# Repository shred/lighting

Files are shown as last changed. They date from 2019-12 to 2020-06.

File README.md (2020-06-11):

# Wall Bias Lighting

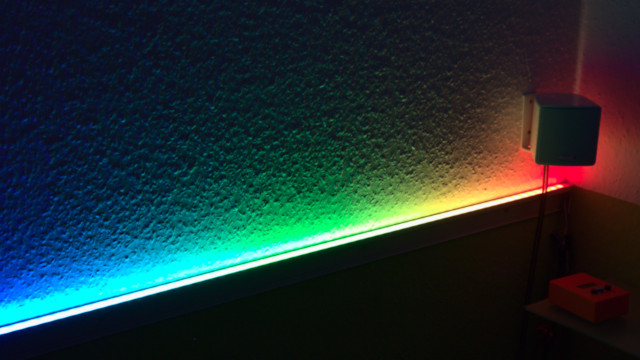
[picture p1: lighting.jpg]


This is a DIY wall bias lighting.

It uses an RGBW LED strip (based on SK6812 LEDs), where every LED can be addressed individually.

# Construction

The lighting consists of a controller module based on an Adafruit [Feather M0 Express](https://www.adafruit.com/product/3403), and a separate RGBW LED strip.

The controller consists of a few components and can be assembled on one-layer strip grid boards. The LED strip only needs a condenser and a resistor, all of them can be wired without a PCB. Just keep the wire between the controller module and LED strip as short as possible.

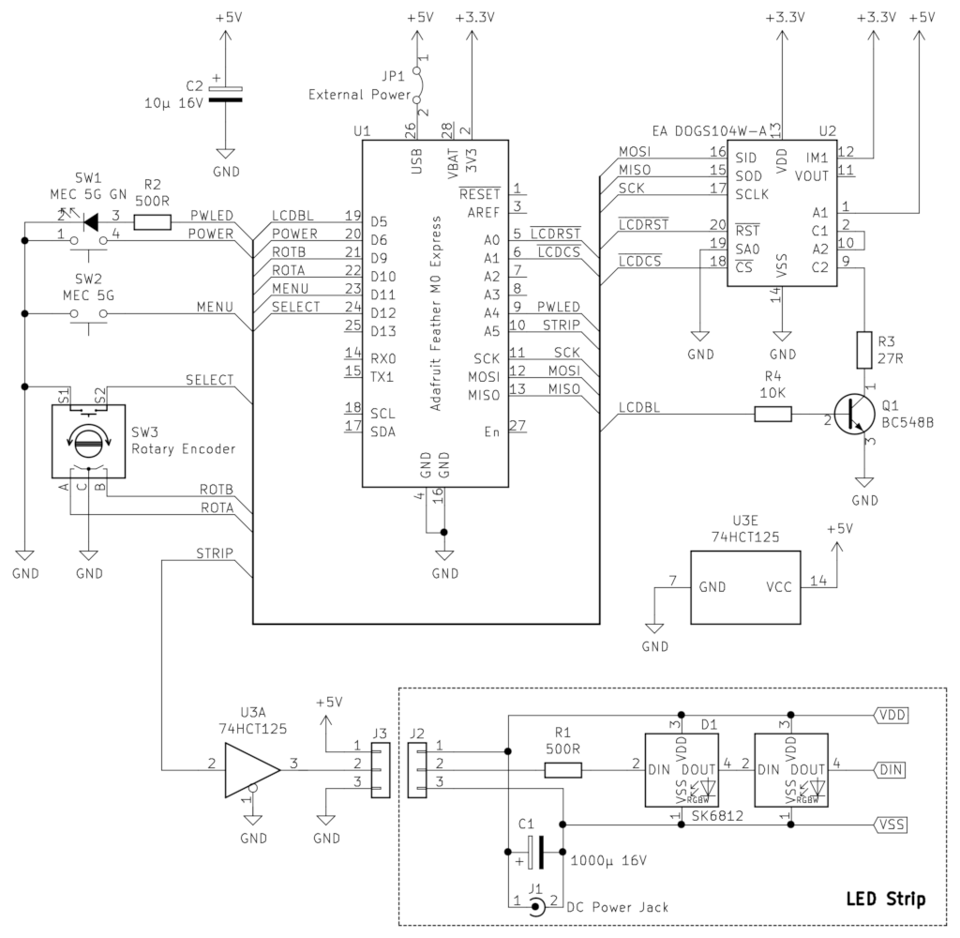
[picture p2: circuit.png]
Circuit Diagram


There is a [blog article](https://shred.zone/blog/page/436/premium-wall-bias-lighting-part-1.html) about the construction that might be helpful.

## Bill of Material

* U1: Adafruit Feather M0 Express
* U2: LCD Display 4x10 with backlight (Electronic Assembly [EA DOGS104W-A](https://www.lcd-module.com/produkte/dog.html) with EA LED36X28A amber backlight, or a similar LCD with SSD1803A controller)
* U3: 74 HCT 125
* Q1: BC 548 B
* D1...: SK6812 based RGBW LED strip, 60 LEDs per meter (NeoPixel compatible)
* R1: 500 Ω
* R2: 500 Ω
* R3: 27 Ω (or matching the LCD display backlight LEDs at 5 V)
* R4: 10 kΩ
* C1: 1000 µF, 16 V
* C2: 10 µF, 16 V
* SW1: Switch with integrated green LED
* SW2: Switch
* SW3: Rotary encoder with switch
* JP1: Jumper. If closed, the Feather is powered by the power brick. Always open the jumper *before* connecting the Feather via USB!
* J1: DC power jack that matches the 5 V power brick
* J2, J3: 3 wire connectors for connecting the LED strip with the controller
* 5 V power brick with at least 18 W per LED strip meter
* Wires and a prototype PCB

In the `case` directory, you will find OpenSCAD files of a 3D printed case for your convenience.

# Programming

The Feather is programmed via the [Arduino IDE](https://www.arduino.cc/en/main/software).

First make sure that the [dependencies](#dependencies) are installed.

Then open the `lighting/lighting.ino` file in the IDE. Locate the line having `#define LED_COUNT`, and set the number of LEDs in your LED strip there. If you forget this step, some of your LEDs may stay black or behave erratic.

Remove the jumper JP1, then connect the Feather to your computer via USB. After that, you can build and install the `lighting` sketch via USB.

> **WARNING:** You must always remove the jumper JP1 *before* connecting the Feather to an USB master, to avoid damage to the USB port!

## Adding new Effects

The sketch comes with a number of predefined effects. You can always add new effects and change existing effects. Just edit `lighting/Effect.h` and `lighting/Effect.cpp` accordingly.

If you add or remove effects, update the `effectList` array in `lighting/lighting.ino` accordingly.

## Dependencies

Please make sure these libraries are installed via the Arduino library manager:

* Adafruit NeoPixel
* Adafruit DMA neopixel library
* MD_REncoder (by majic Designs)

# Usage

When turned on, the LED strip will show an effect. The display shows the name of the current effect, and a bargraph of the brightness.

With the rotary encoder, you can change the brightness. By pressing the encoder switch, the selected brightness value is applied.

Press the menu button to browse the menu. Inside a menu, you can change the value with the rotary encoder, and select your choice by pressing the encoder button. Your change will be discarded when you press the menu button, or wait for about 10 seconds.

These menus are available:

- **Effect**: You can change the lighting effect here.
- **Saturation**: Change the saturation of the colors here.
- **Color Temp**: Change the color temperature. White will appear warmer or cooler depending on the settings.

Use the power button to turn the lighting on or off. When turned off, the power button LED lights up, so you can locate it in a dark room.

# License

This work is licensed under a [Creative Commons Attribution-NonCommercial-ShareAlike license](https://creativecommons.org/licenses/by-nc-sa/4.0/).

> It is explicitly forbidden to sell the assembled hardware or pre-programmed DIY kits for profit. If you need an exemption, please get in contact with me.

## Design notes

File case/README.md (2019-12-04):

In this directory, you will find the [OpenSCAD](https://www.openscad.org) files of a case for the lighting controller.

The `parameter.scad` file contains a lot of parameters that you can adjust to your needs. Each parameter is commented, and you should also see the effect when changing it and looking at the result in OpenSCAD's preview.

`case.scad` contains the construction of the case itself. Rotate it by 180° along the Y axis before printing it, so the top of the case is printed on the heatbed. No supports are needed.

`cover.scad` contains the bottom cover of the case. I recommend to use supports for the screw holes. The printed part should just snap into the case, so there is no actual need for screws though.

I have used PETG and 15% infill for printing, with good results. PLA should work as well.

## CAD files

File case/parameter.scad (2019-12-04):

/*
 * Bias Lighting
 *
 * Copyright (C) 2019 Richard "Shred" Körber
 *   https://github.com/shred/lighting
 *
 * This work is licensed under a Creative Commons Attribution-NonCommercial-ShareAlike
 * license: https://creativecommons.org/licenses/by-nc-sa/4.0/
 */

// All dimensions are in millimeters!

// General case parameters
cornerRadius    = 2;        // Radius of the case edges and corners
wallSize        = 2.5;      // Thickness of the case walls

// Your PCB dimensions
pcbWidth        =  58;      // Width of your controller (X axis)
pcbDepth        =  80;      // Depth of your controller (Y axis)
pcbHeight       =  27;      // Height of your controller (Z axis),
                            //   from the very bottom to the top of the display,
                            //   but without the button caps.

// Padding (distance of PCB to case walls)
paddingXY       =  3;       // Padding at the X and Y axis
paddingZ        =  2;       // Padding at the Z axis

// Buttons
buttonY         = -pcbDepth/2 + 19.6; // Y position of the button caps' centers, relative to case center
buttonX         = 1.4;      // X position of the middle button, relative to case center
buttonDiameter  = 10.2;     // Diameter of the button caps
buttonDistance  = 12.7;     // Distance between center of left and middle button cap
rotaryDiameter  = 10.2;     // Diameter of the rotary encoder cap
rotaryDistance  = 12.7;     // Distance between center of middle button and rotary encoder cap

// LCD
lcdY            = -pcbDepth/2 + 43.5; // Y position of the LCD window's center, relative to case center
windowWidth     = 34.8;     // Width of the LCD window
windowHeight    = 14.1;     // Height of the LCD window
windowThickness = 0.8;      // Thickness of the case around the LCD window
lcdWidth        = 40;       // Total width of the LCD
lcdHeight       = 33;       // Total height of the LCD

// Mounts
pcbThickness    = 1.6;      // Thickness of the bottom PCB
mountDistanceX  = 39.0;     // X distance of the PCB mounting holes
mountOffsetY    = -2.0;     // Y offset of the PCB mounting holes (0 = at the PCB edge)
mountDiameter   = 6;        // Diameter of the mounting columns
mountLength     = 20;       // PCB mounting column length
mountHoleDiameter = 3;      // Screw hole diameter
mountHoleDepth  = 15;       // Screw hole depth
coverMountOffset = 1;       // Offset of cover mounting colums from the case corners
screwHeadDepth  = 1;        // Depth of the insets for the cover screw heads
screwHeadDiameter = 5;      // Diameter of the cover screw heads

// Wire Outlet
outletWidth     = 4.8;      // Width of the wire outlet
outletHeight    = 1.5;      // Height of the wire outlet

// Bottom cover wall
bottomWallSize  = 3;        // Cover's inside wall thickness
bottomWallHeight = 2;       // Cover's inside wall height

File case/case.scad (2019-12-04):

/*
 * Bias Lighting
 *
 * Copyright (C) 2019 Richard "Shred" Körber
 *   https://github.com/shred/lighting
 *
 * This work is licensed under a Creative Commons Attribution-NonCommercial-ShareAlike
 * license: https://creativecommons.org/licenses/by-nc-sa/4.0/
 */

include <parameter.scad>

module roundedSemiBox(size, corner) {
    difference() {
        minkowski() {
            cube([
                size[0] - corner*2,
                size[1] - corner*2,
                (size[2] - corner*2) * 2
            ], center=true);
            sphere(corner);
        }
        translate([0, 0, -size[2]/2]) {
            cube([size[0] + 1, size[1] + 1, size[2]], center=true);
        }
    }
}

module box(innerSize, wall, corner=0) {
    difference() {
        if (corner == 0) {
            translate([0, 0, (innerSize[2] + wall)/2])
                cube([
                    innerSize[0] + wall*2,
                    innerSize[1] + wall*2,
                    innerSize[2] + wall
                ], center = true);
        } else {
            roundedSemiBox([
                innerSize[0] + wall*2,
                innerSize[1] + wall*2,
                innerSize[2] + wall
            ], corner);
        }

        translate([0, 0, innerSize[2]/2 - wall/2]) {
            cube(innerSize, center = true);
        }
    }
}

module buttonCutout(pos, diameter, wall) {
    translate([pos[0], pos[1], pos[2] - 0.5]) {
        cylinder(wall + 1, d=diameter, center=true);
    }
}

module lcdCutout(pos, window, inner, framewall, wall) {
    translate([pos[0], pos[1], pos[2] - 0.5]) {
        cube([window[0], window[1], wall + 1], center=true);
    }
    translate([pos[0], pos[1], pos[2] - wall/2 + framewall/2 - 0.01]) {
        cube([inner[0], inner[1], wall - framewall], center=true);
    }
}

module mountColumn(pos, diameter, length, offset) {
    translate([pos[0], pos[1], offset]) {
        difference() {
            cylinder(d=diameter, h=length+0.3);
            translate([0, 0, -0.1])
                cylinder(d=mountHoleDiameter, h=mountHoleDepth+0.1, $fn=5);
        }
    }
}

caseHeight = pcbHeight + paddingZ + windowThickness;

difference() {
    box([
        pcbWidth + paddingXY*2,
        pcbDepth + paddingXY*2,
        caseHeight
    ], wallSize, cornerRadius);

    translate([-(abs(buttonDistance - rotaryDistance))/2 + buttonX, 0, 0]) {
        buttonCutout([-buttonDistance, buttonY, caseHeight], buttonDiameter, wallSize);
        buttonCutout([0, buttonY, caseHeight], buttonDiameter, wallSize);
        buttonCutout([rotaryDistance, buttonY, caseHeight], rotaryDiameter, wallSize);
    }

    lcdCutout(
        [0, lcdY, caseHeight],
        [windowWidth, windowHeight],
        [lcdWidth, lcdHeight],
        windowThickness,
        wallSize
    );

    translate([0, (pcbDepth+paddingXY)/2 + wallSize, outletHeight/2-0.5]) {
        cube([outletWidth, wallSize + 1, outletHeight+0.5], center=true);
    }
}

caseInnerHeight = pcbHeight + paddingZ;

mountColumn([(mountDistanceX-mountDiameter)/2, (pcbDepth-mountDiameter+mountOffsetY)/2],
    mountDiameter, mountLength + 0.1, caseInnerHeight - mountLength);
mountColumn([-(mountDistanceX-mountDiameter)/2, (pcbDepth-mountDiameter+mountOffsetY)/2],
    mountDiameter, mountLength + 0.1, caseInnerHeight - mountLength);
mountColumn([(mountDistanceX-mountDiameter)/2, -(pcbDepth-mountDiameter+mountOffsetY)/2],
    mountDiameter, mountLength + 0.1, caseInnerHeight - mountLength);
mountColumn([-(mountDistanceX-mountDiameter)/2, -(pcbDepth-mountDiameter+mountOffsetY)/2],
    mountDiameter, mountLength + 0.1, caseInnerHeight - mountLength);

mountColumn([(pcbWidth+paddingXY-coverMountOffset)/2, (pcbDepth+paddingXY-coverMountOffset)/2],
    mountDiameter, caseInnerHeight+0.1, 0);
mountColumn([-(pcbWidth+paddingXY-coverMountOffset)/2, (pcbDepth+paddingXY-coverMountOffset)/2],
    mountDiameter, caseInnerHeight+0.1, 0);
mountColumn([(pcbWidth+paddingXY-coverMountOffset)/2, -(pcbDepth+paddingXY-coverMountOffset)/2],
    mountDiameter, caseInnerHeight+0.1, 0);
mountColumn([-(pcbWidth+paddingXY-coverMountOffset)/2, -(pcbDepth+paddingXY-coverMountOffset)/2],
    mountDiameter, caseInnerHeight+0.1, 0);

$fn=180;

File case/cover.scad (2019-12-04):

/*
 * Bias Lighting
 *
 * Copyright (C) 2019 Richard "Shred" Körber
 *   https://github.com/shred/lighting
 *
 * This work is licensed under a Creative Commons Attribution-NonCommercial-ShareAlike
 * license: https://creativecommons.org/licenses/by-nc-sa/4.0/
 */

include <parameter.scad>

module roundedBottomSemiBox(size, corner) {
    difference() {
        minkowski() {
            cube([
                size[0] - corner*2,
                size[1] - corner*2,
                (size[2] - corner) * 2
            ], center=true);
            sphere(corner);
        }
        translate([0, 0, size[2]/2]) {
            cube([size[0] + 1, size[1] + 1, size[2]], center=true);
        }
    }
}

module screwhole(pos, diameter, length, headDiam, headDepth) {
    translate([pos[0], pos[1], -length]) {
        cylinder(d=diameter, h=length+0.1);
        cylinder(d=headDiam, h=headDepth);
    }
}

difference() {
    roundedBottomSemiBox([
        pcbWidth + paddingXY*2 + wallSize*2,
        pcbDepth + paddingXY*2 + wallSize*2,
        wallSize
    ], cornerRadius);

    screwhole([(pcbWidth+paddingXY-coverMountOffset)/2, (pcbDepth+paddingXY-coverMountOffset)/2],
        mountHoleDiameter, wallSize, screwHeadDiameter, screwHeadDepth);
    screwhole([-(pcbWidth+paddingXY-coverMountOffset)/2, (pcbDepth+paddingXY-coverMountOffset)/2],
        mountHoleDiameter, wallSize, screwHeadDiameter, screwHeadDepth);
    screwhole([(pcbWidth+paddingXY-coverMountOffset)/2, -(pcbDepth+paddingXY-coverMountOffset)/2],
        mountHoleDiameter, wallSize, screwHeadDiameter, screwHeadDepth);
    screwhole([-(pcbWidth+paddingXY-coverMountOffset)/2, -(pcbDepth+paddingXY-coverMountOffset)/2],
        mountHoleDiameter, wallSize, screwHeadDiameter, screwHeadDepth);
}

difference() {
    translate([0, 0, bottomWallHeight/2]) {
        cube([pcbWidth + paddingXY*2, pcbDepth + paddingXY*2, bottomWallHeight], center = true);
    }
    translate([0, 0, bottomWallHeight/2]) {
        cube([pcbWidth + paddingXY*2 - bottomWallSize, pcbDepth + paddingXY*2 - bottomWallSize, bottomWallHeight + 0.1], center = true);
    }

    translate([(pcbWidth+paddingXY-coverMountOffset)/2, (pcbDepth+paddingXY-coverMountOffset)/2, 0])
        cylinder(d=mountDiameter+0.2, h=bottomWallHeight);
    translate([-(pcbWidth+paddingXY-coverMountOffset)/2, (pcbDepth+paddingXY-coverMountOffset)/2, 0])
        cylinder(d=mountDiameter+0.2, h=bottomWallHeight);
    translate([(pcbWidth+paddingXY-coverMountOffset)/2, -(pcbDepth+paddingXY-coverMountOffset)/2, 0])
        cylinder(d=mountDiameter+0.2, h=bottomWallHeight);
    translate([-(pcbWidth+paddingXY-coverMountOffset)/2, -(pcbDepth+paddingXY-coverMountOffset)/2, 0])
        cylinder(d=mountDiameter+0.2, h=bottomWallHeight);

    translate([0, (pcbDepth+paddingXY)/2, bottomWallHeight/2]) {
        cube([outletWidth + 1, bottomWallSize + 1, bottomWallHeight+0.5], center=true);
    }
}

$fn=180;

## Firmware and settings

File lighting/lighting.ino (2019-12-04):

/*
 * Bias Lighting
 *
 * Copyright (C) 2019 Richard "Shred" Körber
 *   https://github.com/shred/lighting
 *
 * This work is licensed under a Creative Commons Attribution-NonCommercial-ShareAlike
 * license: https://creativecommons.org/licenses/by-nc-sa/4.0/
 */

#include <MD_REncoder.h>
#include <SPI.h>

#include "Config.h"
#include "Display.h"
#include "Menu.h"
#include "Effect.h"
#include "Strip.h"


#define DEBOUNCE_MS 100         // debounce time

#define DISPLAY_FADE_AFTER 10000 // Display fade starts after ms
#define DISPLAY_FADE_STEP 2     // Display fade step
#define DISPLAY_FADE_RATE 20    // Display fade rate in ms

#define LED_COUNT 104           // <---- Number of LEDs, CHANGE HERE ----

#define LED_PIN   19            // A5: NeoPixel Strip

#define POWER_BUTTON_PIN 6      //  6: Power Button
#define MENU_BUTTON_PIN 11      // 11: Menu Button
#define POWER_LED_PIN 18        // A4: Power LED

#define ROTARY_BUTTON_PIN 12    // 12: Rotary Button
#define ROTARY_A_PIN 9          //  9: Rotary Pin A
#define ROTARY_B_PIN 10         // 10: Rotary Pin B
#define ENABLE_SPEED 0          // Do not measure rotary speed

#define DISPLAY_RESET_PIN 14    // A0: Display Reset
#define DISPLAY_CS_PIN 15       // A1: Display CS
#define DISPLAY_LIGHT_PIN 5     //  5: Display LED


Config config {};

Strip strip(LED_PIN, LED_COUNT, config);
Display display(DISPLAY_CS_PIN, DISPLAY_RESET_PIN);
MD_REncoder rotary(ROTARY_A_PIN, ROTARY_B_PIN);

Menu *menuList[] = {
    new MenuBrightness(),
    new MenuEffect(),
    new MenuSaturation(),
    new MenuTemperature()
};

Effect *effectList[] = {
    new EffectNightshift(strip, config),
    new EffectJustWhite(strip, config),
    new EffectRainbow(strip, config),
    new EffectStarlight(strip, config)
};

int displayBrightness;
unsigned long displayNextTime;


/**
 * Waits until all buttons have been released. After that, a delay of DEBOUNCE_MS is added
 * to debounce the key.
 */
void waitUntilButtonsReleased() {
    while (digitalRead(POWER_BUTTON_PIN) == LOW
          || digitalRead(MENU_BUTTON_PIN) == LOW
          || digitalRead(ROTARY_BUTTON_PIN) == LOW) {
        // busy wait for buttons to be released
    }
    delay(DEBOUNCE_MS); // debounce key
}

/**
 * Activates the currently selected menu.
 */
void activateMenu() {
    config.menus[config.currentMenu]->activate(config);
    config.menus[config.currentMenu]->render(display);
}

/**
 * Applies the currently selected effect to the LED strip.
 */
void applyEffect() {
    config.effects[config.currentEffect]->apply();
}

/**
 * Turns the lighting off. The strip is turned black and the LCD is turned off.
 * The power LED is turned on, and then a busy wait loop waits for the power button to be
 * pressed again. After that, the LCD is turned on and the current effect is applied to
 * the LED strip.
 */
void powerOff() {
    // Turn power LED on
    digitalWrite(POWER_LED_PIN, HIGH);

    // Turn display LED off
    displayLightOff();

    // Turn LED strip off
    strip.black();

    // Turn display off
    display.sleep();

    // Wait for all buttons to be released
    waitUntilButtonsReleased();

    // Wait for the power button to be pressed
    while (digitalRead(POWER_BUTTON_PIN) == HIGH) {
        // busy wait
    }
    delay(DEBOUNCE_MS);

    // Turn power LED off
    digitalWrite(POWER_LED_PIN, LOW);

    // Turn display on
    display.wakeup();

    // Turn on LED strip
    applyEffect();
}

/**
 * Checks if the display backlight needs to be faded out, and fades accordingly.
 *
 * @return true if the display fadeout has just been completed. This can be used to reset
 * to a standard menu when the display fader timed out.
 */
boolean displayLightCheck() {
    if (displayNextTime != 0 && displayNextTime <= millis()) {
        displayBrightness -= DISPLAY_FADE_STEP;
        if (displayBrightness > 0 && displayBrightness < 256) {
            analogWrite(DISPLAY_LIGHT_PIN, displayBrightness);
            displayNextTime += DISPLAY_FADE_RATE;
        } else if (displayBrightness <= 0) {
            analogWrite(DISPLAY_LIGHT_PIN, 0);
            displayNextTime = 0;
            return true;
        }
    }
    return false;
}

/**
 * Turns the display backlight on. After a while, the backlight will fade out
 * automatically. This function can be invoked multiple times, to retrigger the backlight
 * fade timeout.
 */
void displayLightOn() {
    analogWrite(DISPLAY_LIGHT_PIN, 255);
    displayBrightness = 255;
    displayNextTime = millis() + DISPLAY_FADE_AFTER;
}

/**
 * Turns the display backlight off immediately.
 */
void displayLightOff() {
    analogWrite(DISPLAY_LIGHT_PIN, 0);
    displayNextTime = 0;
}

/**
 * Sets up the sheet.
 */
void setup() {
    #if defined(__AVR_ATtiny85__) && (F_CPU == 16000000)
        clock_prescale_set(clock_div_1);
    #endif

    pinMode(POWER_BUTTON_PIN, INPUT_PULLUP);
    pinMode(MENU_BUTTON_PIN, INPUT_PULLUP);
    pinMode(POWER_LED_PIN, OUTPUT);
    pinMode(ROTARY_BUTTON_PIN, INPUT_PULLUP);
    pinMode(DISPLAY_LIGHT_PIN, OUTPUT);

    SPI.begin();
    rotary.begin();
    display.reset();

    config.menus = menuList;
    config.menuCount = sizeof(menuList) / sizeof(menuList[0]);

    config.effects = effectList;
    config.effectCount = sizeof(effectList) / sizeof(effectList[0]);
    config.currentEffect = 0;

    displayLightOff();

    activateMenu();
    applyEffect();
    displayLightOn();
}

/**
 * Main loop.
 */
void loop() {
    uint8_t rotChange = rotary.read();
    if (rotChange != DIR_NONE) {
        config.menus[config.currentMenu]->change(rotChange == DIR_CW ? 1 : -1);
        config.menus[config.currentMenu]->render(display);
        displayLightOn();
    }

    if (digitalRead(POWER_BUTTON_PIN) == LOW) {
        powerOff();
        displayLightOn();
        waitUntilButtonsReleased();
    }

    if (digitalRead(MENU_BUTTON_PIN) == LOW) {
        config.currentMenu++;
        if (config.currentMenu >= config.menuCount) {
            config.currentMenu = 0;
        }
        activateMenu();
        displayLightOn();
        waitUntilButtonsReleased();
    }

    if (digitalRead(ROTARY_BUTTON_PIN) == LOW) {
        config.menus[config.currentMenu]->apply(config);
        applyEffect();
        config.currentMenu = 0;
        activateMenu();
        displayLightOn();
        waitUntilButtonsReleased();
    }

    if (displayLightCheck()) {
        config.currentMenu = 0;
        activateMenu();
    };
}

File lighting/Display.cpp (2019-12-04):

/*
 * Bias Lighting
 *
 * Copyright (C) 2019 Richard "Shred" Körber
 *   https://github.com/shred/lighting
 *
 * This work is licensed under a Creative Commons Attribution-NonCommercial-ShareAlike
 * license: https://creativecommons.org/licenses/by-nc-sa/4.0/
 */

#include "Display.h"

#include <Arduino.h>
#include <SPI.h>

#define RESET_TIME_MS 50        // reset signal is 50 ms
#define BITRATE 1000000         // max bitrate is 1 MHz

Display::Display (int csPin, int resetPin) {
    this->csPin = csPin;
    this->resetPin = resetPin;

    pinMode(this->resetPin, OUTPUT);
    pinMode(this->csPin, OUTPUT);
    digitalWrite(this->resetPin, HIGH);
    digitalWrite(this->csPin, HIGH);
}

void Display::reset() const {
    digitalWrite(resetPin, LOW);
    delay(RESET_TIME_MS);
    digitalWrite(resetPin, HIGH);
    delay(RESET_TIME_MS);

    open();
    sendCommand(0x3A);  // FS: IS=0 RE=1, 8 bit, 4 lines
    sendCommand(0x09);  // 5 pixel width, no inversion, 4 line mode
    sendCommand(0x06);  // Normal order, Reverse segment direction
    sendCommand(0x1E);  // 1/6 bias
    sendCommand(0x39);  // FS: IS=1 RE=0, 8 bit, 4 lines
    sendCommand(0x1B);  // Divider 540kHz (POR), 1/6 bias
    sendCommand(0x7A);  // Contrast 0x.A
    sendCommand(0x56);  // Contrast 0x2A, ICONs off, DC/DC on
    sendCommand(0x6E);  // Divider on, IR6 (1+Rb/Ra = 5.3)
    sendCommand(0x38);  // FS: IS=0 RE=0, 8 bit, 4 lines, double height font
    sendCommand(0x01);  // Clear Display
    sendCommand(0x0C);  // Display on, Cursor off, Cursor blink off
    sendCommand(0x3A);  // FS: IS=0 RE=1, 8 bit, 4 lines
    sendCommand(0x17);  // Display: 3 lines, middle double height (keep bias)
    sendCommand(0x72);  // ROM Selection
    sendChar(0x00);     // Select ROM A
    sendCommand(0x3C);  // FS: IS=0 RE=0, 8 bit, 4 lines, double height
    close();
}

void Display::sleep() const {
    open();
    sendCommand(0x08);  // Display Off
    sendCommand(0x3A);  // FS: IS=0 RE=1, 8 bit, 4 lines
    sendCommand(0x03);  // Power Down
    close();
}

void Display::wakeup() const {
    open();
    sendCommand(0x02);  // Power Up
    sendCommand(0x3C);  // FS: IS=0 RE=0, 8 bit, 4 lines, double height
    sendCommand(0x0C);  // Display on, Cursor off, Cursor blink off
    close();
}

void Display::print(int row, char *text) const {
    open();
    sendCommand(0x80 + row * 0x20);
    int count = 10;
    for (char* ch = text; *ch != '\0' && count > 0; ch++, count--) {
        sendChar(*ch);
    }
    while (count-- > 0) {
        sendChar(' ');
    }
    close();
}

void Display::bargraph(int row, int percent) const {
    char output[11];

    if (percent < 0) {
        percent = 0;
    }
    if (percent > 100) {
        percent = 100;
    }

    int blocks = percent / 10;

    for (int i = 0; i < 10; i++) {
        output[i] = i < blocks ? 0xD6 : ' ';
    }

    int singles = (percent / 2) % 5;
    if (singles == 1) {
        output[blocks] = 0xDA;
    } else if (singles == 2) {
        output[blocks] = 0xD9;
    } else if (singles == 3) {
        output[blocks] = 0xD8;
    } else if (singles == 4) {
        output[blocks] = 0xD7;
    }

    output[10] = '\0';
    print(row, output);
}

void Display::balance(int row, int percent) const {
    char output[11];

    if (percent < -100) {
        percent = -100;
    }
    if (percent > 100) {
        percent = 100;
    }

    for (int i = 0; i < 10; i++) {
        output[i] = ' ';
    }

    if (percent == 0) {
        output[4] = 0x10;
        output[5] = 0x11;
    } else if (percent < 0) {
        int cnt = (-percent + 9) / 10;
        for (int i = 0; i < cnt && i < 10; i++) {
            output[4 - i / 2] = (i == cnt - 1 && i % 2 == 0) ? 0x94 : 0xD0;
        }
    } else {
        int cnt = (percent + 9) / 10;
        for (int i = 0; i < cnt && i < 10; i++) {
            output[5 + i / 2] = (i == cnt - 1 && i % 2 == 0) ? 0x94 : 0xD0;
        }
    }

    output[10] = '\0';
    print(row, output);
}

void Display::open() const {
    SPI.beginTransaction(SPISettings(BITRATE, LSBFIRST, SPI_MODE3));
    digitalWrite(csPin, LOW);
}

void Display::close() const {
    digitalWrite(csPin, HIGH);
    SPI.endTransaction();
}

void Display::wait() const {
    SPI.transfer(0x3F);
    unsigned int result = SPI.transfer(0x00);
    while (result & 0x01 != 0) {
        // TODO: We need some kind of timeout...
        result = SPI.transfer(0x00);
    }
}

void Display::sendCommand(char cmd) const {
    SPI.transfer(0x1F);
    SPI.transfer(cmd & 0x0F);
    SPI.transfer((cmd >> 4) & 0x0F);
    wait();
}

void Display::sendChar(char chr) const {
    SPI.transfer(0x5F);
    SPI.transfer(chr & 0x0F);
    SPI.transfer((chr >> 4) & 0x0F);
    wait();
}
